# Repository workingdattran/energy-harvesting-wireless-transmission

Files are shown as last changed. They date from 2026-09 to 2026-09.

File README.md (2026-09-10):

# Energy Harvesting & Wireless Data Transmission System

## Overview
This repository contains the hardware schematics and firmware source code for a self-sustaining IoT system that harvests solar energy and transmits real-time telemetry data[cite: 1]. Developed as a course project for Information Theory at Hanoi University of Science and Technology (HUST)[cite: 1], the system utilizes a Joule Thief circuit to boost low-voltage solar power into a supercapacitor, and an ESP32-S3 microcontroller to transmit voltage data via the ESP-NOW protocol[cite: 1]. 

To optimize bandwidth and energy consumption, the firmware implements data compression using Differential Pulse Code Modulation (DPCM) combined with Huffman coding, compressing 32-bit floating-point data down to a single bit during stable charging states[cite: 1].

## System Architecture

The architecture is built upon the classic Shannon communication model, consisting of two main nodes[cite: 1]:

### 1. Transmitter Node (ESP32-S3 + Joule Thief)
*   **Energy Harvesting:** A 3V / 210 mA polycrystalline solar panel powers a custom blocking oscillator (Joule Thief) using a 2N2222 NPN transistor, a bifilar ferrite toroid (15 turns), and a 1N5822 Schottky diode[cite: 1].
*   **Storage & Protection:** Energy is stored in a 5.5V - 1F supercapacitor[cite: 1]. A TL431 shunt regulator paired with a 47kΩ voltage divider caps the voltage at 5.0V to protect the supercapacitor, while keeping static leakage current minimal (~0.05 mA)[cite: 1].
*   **ADC Processing:** The ESP32-S3 reads the capacitor's voltage via its 12-bit ADC, utilizing a 64-sample oversampling technique and linear calibration to eliminate quantization noise[cite: 1].
*   **Source Coding:** 
    *   **DPCM:** Calculates the prediction error of the voltage based on charging inertia[cite: 1].
    *   **Huffman Coding:** Encodes the error into variable-length bit streams, dynamically reducing payload size[cite: 1].

### 2. Receiver Node (ESP32-S3)
*   Operates continuously in RX mode[cite: 1].
*   Receives payload via ESP-NOW, decodes the Huffman sequence, reconstructs the original voltage using inverse DPCM, and outputs performance metrics via UART (115200 baud) for logging[cite: 1].

## Hardware Bill of Materials (BOM)
| Component | Specification | Purpose |
| :--- | :--- | :--- |
| **MCU** | 2x ESP32-S3 Dev Module | Processing & ESP-NOW Tx/Rx[cite: 1] |
| **Solar Panel** | Polycrystalline 3V / 210mA (70x70mm) | Power source[cite: 1] |
| **Transistor** | NPN 2N2222 (TO-92) | Oscillator switch[cite: 1] |
| **Diode** | Schottky 1N5822 | High-frequency rectification[cite: 1] |
| **Inductor** | Bifilar wound ferrite core (15 turns) | Flyback transformer[cite: 1] |
| **Capacitor** | 5.5V - 1F Supercapacitor | Energy storage[cite: 1] |
| **IC** | TL431 Shunt Regulator | Overvoltage protection[cite: 1] |
| **Resistors** | 1kΩ, 2x 47kΩ | Base biasing & Voltage divider[cite: 1] |

## Performance Metrics
Based on laboratory experiments processing 2,286 packets, the system achieved the following metrics[cite: 1]:
*   **Maximum Compression Ratio:** 32.0x (Payload reduced from 32-bit float to 1-bit during ideal tracking)[cite: 1].
*   **Transmission Latency:** 804 µs median delay[cite: 1].
*   **Reliability:** 0.31% total packet error rate (PER) with an automated MAC-layer CRC integrity check[cite: 1].
*   **Throughput:** 14.93 Bytes per second (average), effectively freeing up the 2.4 GHz spectrum[cite: 1].

## Build & Flash Instructions
1.  Clone this repository to your local machine.
2.  Open the project using **PlatformIO** or **Arduino IDE** (ensure ESP32 board support is installed).
3.  Upload the `Tx_Node` directory code to the first ESP32-S3.
4.  Upload the `Rx_Node` directory code to the second ESP32-S3.
5.  Open the Serial Monitor (115200 baud) on the Receiver Node to view real-time decoded voltage and transmission metrics.

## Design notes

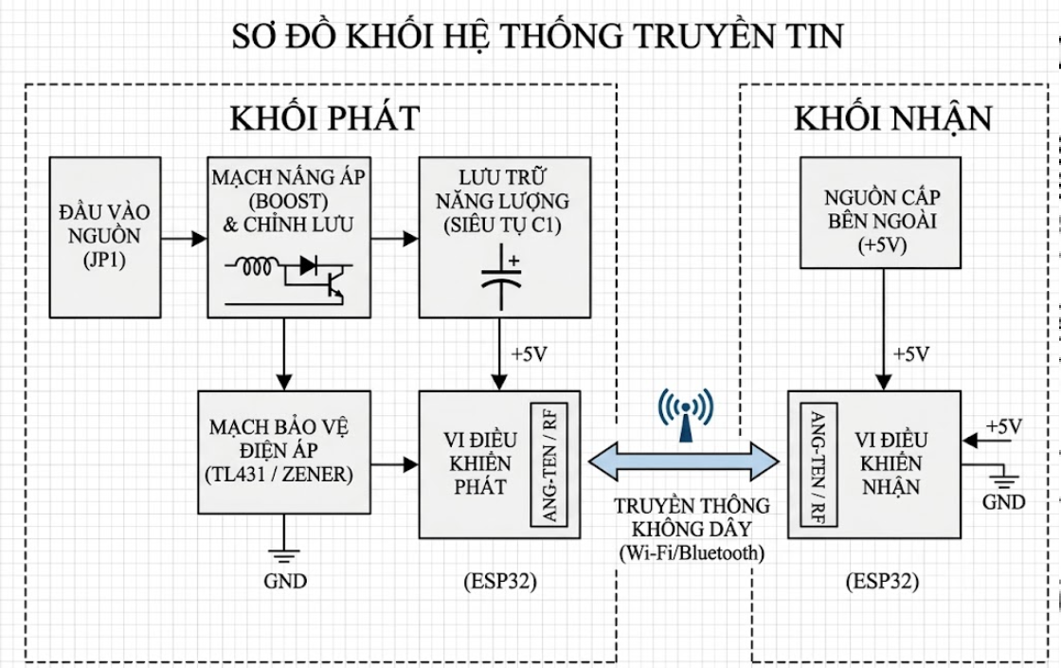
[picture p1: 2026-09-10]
energy harvesting/Altium designed/assets/sodo_khoi.png

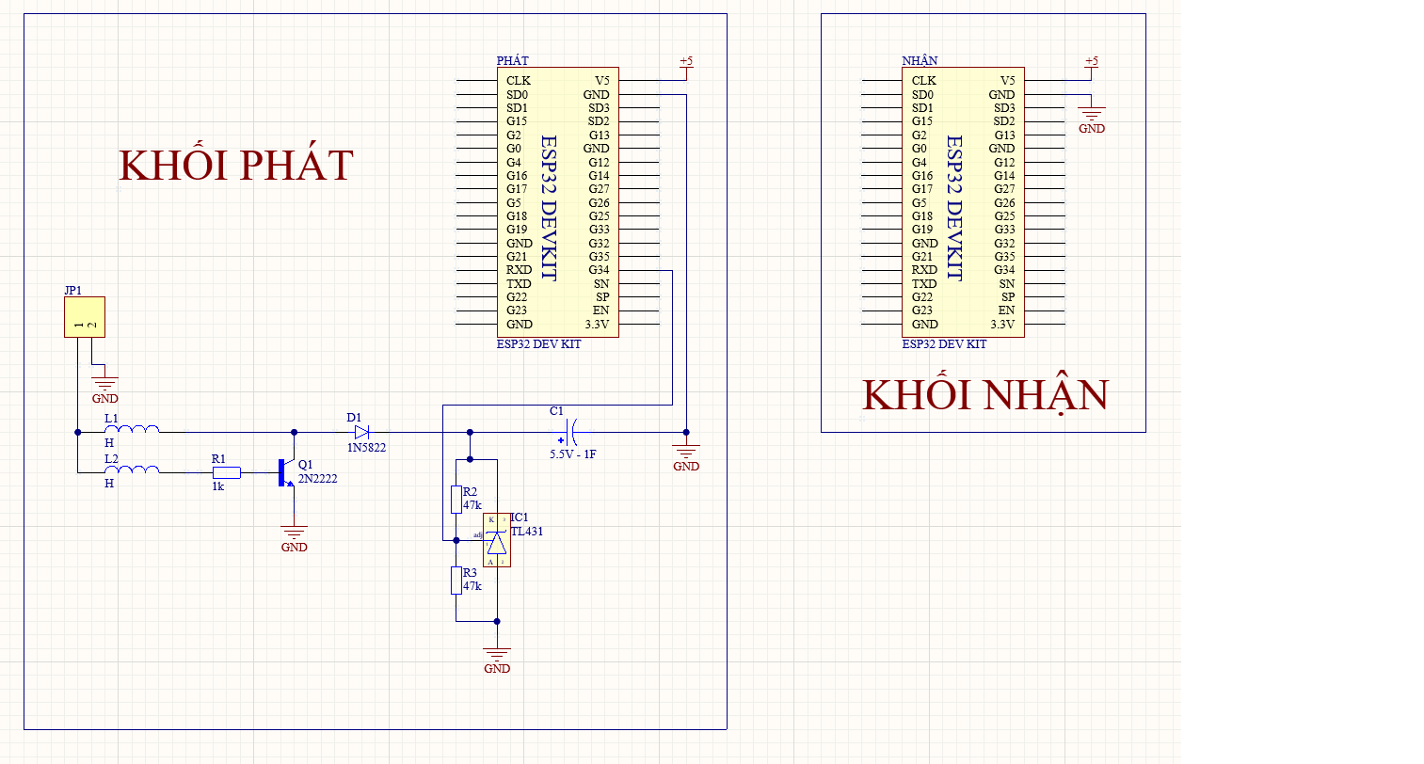
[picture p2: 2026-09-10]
energy harvesting/Altium designed/assets/sodonguyenly.png

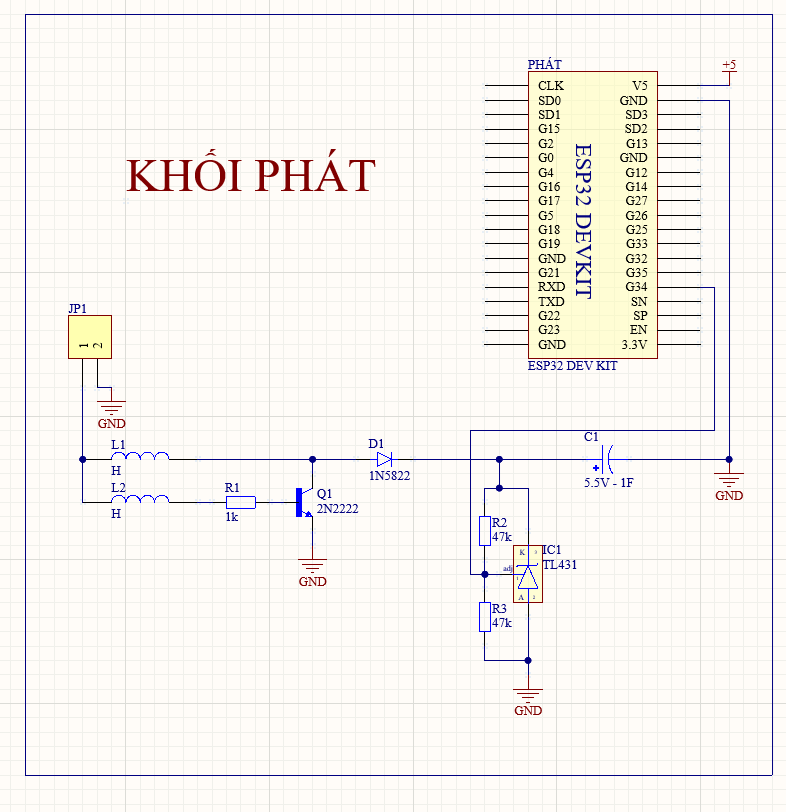
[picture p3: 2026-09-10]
energy harvesting/Altium designed/assets/PHÁT.png

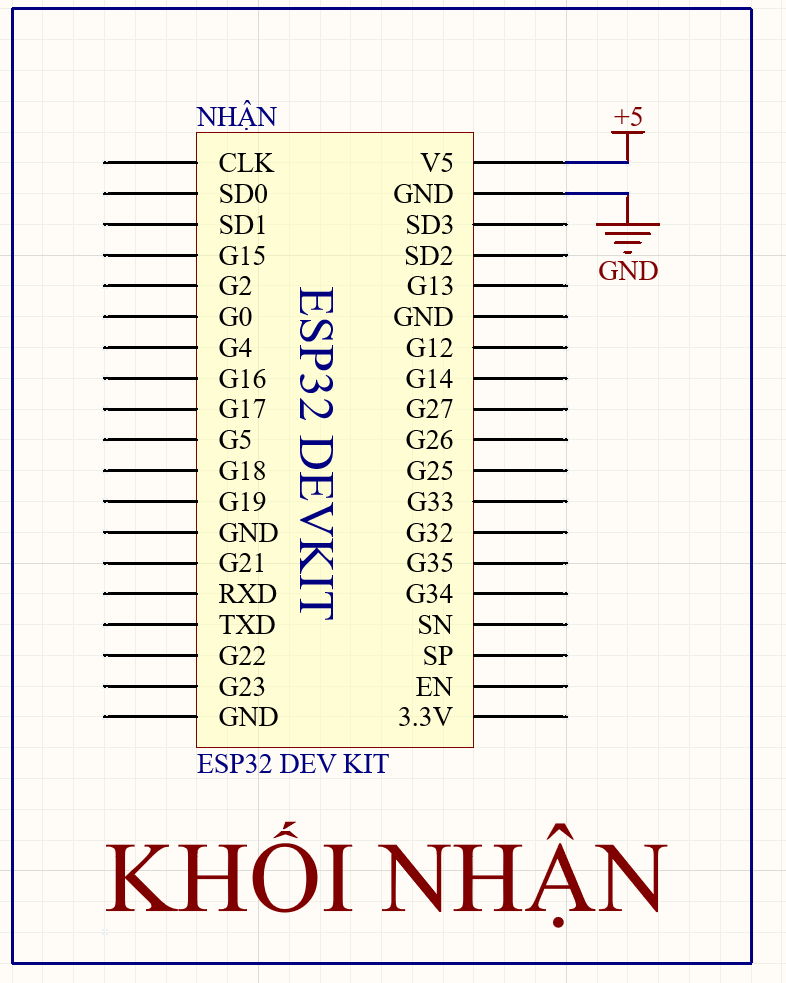
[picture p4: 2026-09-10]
energy harvesting/Altium designed/assets/NHẬN.png

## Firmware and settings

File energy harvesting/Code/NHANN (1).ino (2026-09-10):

#include <esp_now.h>
#include <WiFi.h>
#include <esp_wifi.h>
#include <HTTPClient.h>
#include <ArduinoJson.h>

// --- THÔNG TIN WIFI VÀ GOOGLE SHEETS ---
const char* ssid = "depzailatengoi";
const char* password = "tranducdat";
const char* scriptUrl = "https://script.google.com/macros/s/AKfycbxbDeGb_7TwyR9PDk_l7dfxE3b5P4eicFt4YnIJgVGBVs9WbP96MlSlnLDNgulAzeRiyw/exec";

unsigned long lastPrintTime = 0;
const unsigned long printInterval = 250;

#pragma pack(push, 1)
typedef struct struct_message {
  uint32_t packetID;
  uint8_t isKeyFrame; 
  float lossRate;     
  uint32_t txDelay;   
  union {
    float dienApGoc;
    struct {
      uint16_t code;
      uint8_t bitLen;
    } huffman;
  } payload;
} struct_message;
#pragma pack(pop)

struct_message myData;

float dienApHienTai = 0.0;
int dienApHienTai_mV = 0;
int tocDoTruoc_mV = 0;

float phat_lossRate = 0.0;
uint32_t phat_txDelay = 0;

uint32_t expectedPacketID = 0;
unsigned long tongSoGoiBiMat = 0;
unsigned long tongSoGoiDaNhan = 0;
unsigned long tongSoByteDaNhan = 0;
unsigned long thoiGianBatDauNhan = 0;

float packetLossRate = 0.0;
float throughput = 0.0;

volatile bool coDuLieuMoi = false; 
volatile bool laGoiGoc = false; 

int decodeHuffman(uint16_t code, uint8_t bitLen) {
  if (bitLen == 1 && code == 0b0) return 0;
  if (bitLen == 2 && code == 0b10) return 1;
  if (bitLen == 3 && code == 0b110) return -1;
  if (bitLen == 4 && code == 0b1110) return 2;
  if (bitLen == 5 && code == 0b11110) return -2;
  if (bitLen == 13) return (int8_t)(code & 0xFF); 
  return 0; 
}

void OnDataRecv(const esp_now_recv_info_t *esp_now_info, const uint8_t *incomingData, int len) {
  unsigned long thoiGianHienTai = millis();
  memcpy(&myData, incomingData, sizeof(myData));
  
  if (tongSoGoiDaNhan == 0) thoiGianBatDauNhan = thoiGianHienTai;

  laGoiGoc = myData.isKeyFrame; 
  phat_lossRate = myData.lossRate; 
  phat_txDelay = myData.txDelay;   

  // 1. GIẢI MÃ QUÁN TÍNH DPCM
  if (laGoiGoc) {
    dienApHienTai = myData.payload.dienApGoc;
    dienApHienTai_mV = round(dienApHienTai * 1000.0);
    tocDoTruoc_mV = 0; 
  } else {
    int saiSo_mV = decodeHuffman(myData.payload.huffman.code, myData.payload.huffman.bitLen);
    
    int dienApDuDoan_mV = dienApHienTai_mV + tocDoTruoc_mV;
    int dienApMoi_mV = dienApDuDoan_mV + saiSo_mV;
    int dienApCu_mV = dienApHienTai_mV; 
    
    dienApHienTai_mV = dienApMoi_mV;
    dienApHienTai = dienApHienTai_mV / 1000.0;
    
    tocDoTruoc_mV = dienApHienTai_mV - dienApCu_mV; 
  }

  // 2. THỐNG KÊ TRUYỀN TIN
  if (tongSoGoiDaNhan == 0) expectedPacketID = myData.packetID;
  if (myData.packetID > expectedPacketID) tongSoGoiBiMat += (myData.packetID - expectedPacketID);
  
  expectedPacketID = myData.packetID + 1;
  tongSoGoiDaNhan++;

  packetLossRate = ((float)tongSoGoiBiMat / (tongSoGoiDaNhan + tongSoGoiBiMat)) * 100.0;

  tongSoByteDaNhan += len;
  float thoiGianChay_s = (thoiGianHienTai - thoiGianBatDauNhan) / 1000.0;
  if (thoiGianChay_s > 0) throughput = tongSoByteDaNhan / thoiGianChay_s;

  coDuLieuMoi = true;
}

// HÀM ĐẨY DỮ LIỆU LÊN GOOGLE SHEETS
void sendToGoogleSheets(String loaiGoiStr) {
  if (WiFi.status() == WL_CONNECTED) {
    HTTPClient http;

    // --- 1. GỬI DỮ LIỆU CỦA NODE PHÁT (TX) ---
    http.begin(scriptUrl);
    http.addHeader("Content-Type", "application/json");
    StaticJsonDocument<200> docTX;
    docTX["nodeType"] = "TX";
    docTX["packetID"] = myData.packetID;
    docTX["dienAp"] = dienApHienTai;
    docTX["loaiGoi"] = loaiGoiStr;
    docTX["txLoss"] = phat_lossRate;
    docTX["txDelay"] = phat_txDelay;
    
    String reqTX; serializeJson(docTX, reqTX);
    http.POST(reqTX);
    http.end();

    // --- 2. GỬI DỮ LIỆU CỦA NODE NHẬN (RX) ---
    http.begin(scriptUrl);
    http.addHeader("Content-Type", "application/json");
    StaticJsonDocument<200> docRX;
    docRX["nodeType"] = "RX";
    docRX["packetID"] = myData.packetID;
    docRX["dienAp"] = dienApHienTai;
    docRX["loaiGoi"] = loaiGoiStr;
    docRX["rxLoss"] = packetLossRate;
    docRX["bangThong"] = throughput;
    
    String reqRX; serializeJson(docRX, reqRX);
    http.POST(reqRX);
    http.end();
  } else {
    Serial.println("Lỗi kết nối WiFi, không thể gửi lên Sheets");
  }
}

void setup() {
  Serial.begin(115200);
  
  // 1. Kết nối WiFi để lấy Internet
  WiFi.mode(WIFI_STA);
  WiFi.begin(ssid, password);
  
  Serial.print("Connecting to WiFi");
  while (WiFi.status() != WL_CONNECTED) {
    delay(500);
    Serial.print(".");
  }
  Serial.println("\nWiFi Connected!");
  delay(1000);
  
  // Lấy kênh WiFi hiện tại của Router
  int wifiChannel = WiFi.channel();
  
  // 2. Khởi tạo ESP-NOW ĐỒNG BỘ với kênh WiFi của Router
  esp_wifi_set_promiscuous(true);
  esp_wifi_set_channel(wifiChannel, WIFI_SECOND_CHAN_NONE);
  esp_wifi_set_promiscuous(false);

  if (esp_now_init() != ESP_OK) {
    Serial.println("Lỗi khởi tạo ESP-NOW");
    return;
  }
  esp_now_register_recv_cb(OnDataRecv);
  
  Serial.print("--- KÊNH HOẠT ĐỘNG: "); Serial.print(wifiChannel); Serial.println(" ---");
  Serial.println("--- NHẬN: ĐÃ KÍCH HOẠT GIẢI MÃ PREDICTIVE CODING ---");
}

void loop() {
  // Tạo biến static để đếm thời gian riêng cho việc gửi lên Sheets
  static unsigned long lastSendTime = 0;
  const unsigned long sendInterval = 5000; // Thay đổi số này (ms) để chỉnh tần suất gửi Sheets (ví dụ 5000 = 5 giây)

  if (millis() - lastPrintTime >= printInterval) { 
    lastPrintTime = millis();
    
    if (coDuLieuMoi) {
      coDuLieuMoi = false; 
      String loaiGoiStr = laGoiGoc ? "GOC" : "HUF";

      // 1. In log ra Serial (Chạy mượt mà theo đúng printInterval)
      Serial.print("Ap: ");
      Serial.print(dienApHienTai, 3); Serial.print("V | ");
      Serial.print("GOI: "); Serial.print(loaiGoiStr);
      Serial.print(" | MAT GOI RX: "); Serial.print(packetLossRate, 1); Serial.print("% | ");
      Serial.print("BANG THONG: "); Serial.print(throughput, 1); Serial.println(" Bps");

      // 2. Gửi dữ liệu lên Sheets (Được tách riêng rẽ, chỉ chạy khi đủ thời gian sendInterval)
      if (millis() - lastSendTime >= sendInterval) {
        lastSendTime = millis();
        sendToGoogleSheets(loaiGoiStr);
      }
    }
  }
}

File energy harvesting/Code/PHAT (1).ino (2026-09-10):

#include <esp_now.h>
#include <WiFi.h>
#include <esp_wifi.h>

// Đã đổi sang chân 34 để tránh xung đột với TX0 (chân 1) của cổng Serial
#define PIN_DO_AP 6 
float HE_SO_PHAN_AP = 2.0; 
float VI_CHINH_OFFSET1 = 0.007; 

uint8_t receiverAddress[] = {0x70, 0x4B, 0xCA, 0x6E, 0x3B, 0xC8};

#pragma pack(push, 1)
typedef struct struct_message {
  uint32_t packetID;
  uint8_t isKeyFrame; 
  float lossRate;     
  uint32_t txDelay;   
  union {
    float dienApGoc;  
    struct { 
      uint16_t code;  
      uint8_t bitLen; 
    } huffman;
  } payload;
} struct_message;
#pragma pack(pop)

struct_message myData;
esp_now_peer_info_t peerInfo;

// Các biến phục vụ Mã hóa dự đoán (DPCM)
int dienApTruoc_mV = 0;
int tocDoTruoc_mV = 0; 
unsigned long tongSoGoiDaGui = 0;
unsigned long soGoiLoiACK = 0;

// Các biến volatile để sử dụng đồng bộ giữa callback và loop
volatile uint32_t thoiGianTreTruocDo = 0; 
volatile unsigned long timeStart = 0;    

// THÊM: Các biến phục vụ việc định thời gian bằng millis()
unsigned long thoiGianDoCu = 0;
unsigned long thoiGianGuiCu = 0;
float dienApDaLocHienTai = 0.0;

void encodeHuffman(int saiSo_mV) {
  myData.isKeyFrame = 0;
  if (saiSo_mV == 0)       { myData.payload.huffman.bitLen = 1; myData.payload.huffman.code = 0b0; }
  else if (saiSo_mV == 1)  { myData.payload.huffman.bitLen = 2; myData.payload.huffman.code = 0b10; }
  else if (saiSo_mV == -1) { myData.payload.huffman.bitLen = 3; myData.payload.huffman.code = 0b110; }
  else if (saiSo_mV == 2)  { myData.payload.huffman.bitLen = 4; myData.payload.huffman.code = 0b1110; }
  else if (saiSo_mV == -2) { myData.payload.huffman.bitLen = 5; myData.payload.huffman.code = 0b11110; }
  else { 
    uint8_t safeSaiSo = (uint8_t)saiSo_mV;
    myData.payload.huffman.bitLen = 13; 
    myData.payload.huffman.code = (0b11111 << 8) | safeSaiSo; 
  }
}

// Hàm callback chuẩn của ESP-NOW để nhận phản hồi (ACK)
void OnDataSent(const wifi_tx_info_t *txInfo, esp_now_send_status_t status) {
  if (status == ESP_NOW_SEND_SUCCESS) {
    // Nhận được ACK -> Tính thời gian RTT chia đôi để ra độ trễ 1 chiều
    thoiGianTreTruocDo = (uint32_t)((micros() - timeStart) / 2); 
  } else {
    // Mất gói tin (không nhận được ACK)
    soGoiLoiACK++;
  }
}

// BỘ LỌC: TRIMMED MEAN KẾT HỢP EMA (CHỐNG NHIỄU TUYỆT ĐỐI)
float dienApDaLoc = -1.0; 
const float ALPHA = 0.5; 

float docDienApChuan(int pin) {
  int rawValues[64];
  
  // 1. Lấy 64 mẫu liên tục
  for(int i = 0; i < 64; i++) {
    rawValues[i] = analogReadMilliVolts(pin);
  }
  
  // 2. Bubble Sort
  for(int i = 0; i < 63; i++) {
    for(int j = i + 1; j < 64; j++) {
      if(rawValues[i] > rawValues[j]) {
        int temp = rawValues[i];
        rawValues[i] = rawValues[j];
        rawValues[j] = temp;
      }
    }
  }
  
  // 3. Trimmed Mean (Lọc 32 mẫu giữa)
  long tong_mV = 0;
  for(int i = 16; i < 48; i++) {
    tong_mV += rawValues[i];
  }
  float dienApTucThoi = (tong_mV / 32.0) / 1000.0;
  
  // 4. SMART EMA FILTER (Lọc thông minh)
  if (dienApDaLoc < 0) {
    dienApDaLoc = dienApTucThoi; // Gán lần đầu
  } else {
    // Nếu độ lệch giữa số cũ và số thực tế lớn hơn 0.03V (30mV)
    // -> Báo hiệu có sự kiện cắm/rút tụ đột ngột -> Nhảy số ngay lập tức
    if (abs(dienApTucThoi - dienApDaLoc) > 0.03) {
      dienApDaLoc = dienApTucThoi; 
    } 
    // Nếu biến động nhỏ -> Do nhiễu -> Kích hoạt lọc EMA chậm rãi
    else {
      dienApDaLoc = (ALPHA * dienApTucThoi) + ((1.0 - ALPHA) * dienApDaLoc);
    }
  }
  
  return dienApDaLoc;
}

void setup() {
  Serial.begin(115200);
  analogSetPinAttenuation(PIN_DO_AP, ADC_11db);
  WiFi.mode(WIFI_STA);
  esp_wifi_set_ps(WIFI_PS_NONE);
  esp_wifi_set_channel(11, WIFI_SECOND_CHAN_NONE);
  
  if (esp_now_init() != ESP_OK) return;
  esp_now_register_send_cb(OnDataSent);
  
  memcpy(peerInfo.peer_addr, receiverAddress, 6);
  peerInfo.peer_addr[0] = receiverAddress[0];
  peerInfo.channel = 11;  
  peerInfo.encrypt = false;
  esp_now_add_peer(&peerInfo);
  
  Serial.println("--- PHÁT: ĐÃ KÍCH HOẠT LỌC NHIỄU & DPCM + HUFFMAN ---");
}

void loop() {
  unsigned long thoiGianHienTai = millis();

  // ==============================================================
  // CHU KỲ 1: ĐO VÀ LỌC ĐIỆN ÁP LIÊN TỤC MỖI 20ms (50 lần/giây)
  // ==============================================================
  if (thoiGianHienTai - thoiGianDoCu >= 20) {
    dienApDaLocHienTai = docDienApChuan(PIN_DO_AP);
    thoiGianDoCu = thoiGianHienTai;
  }

  // ==============================================================
  // CHU KỲ 2: TÍNH TOÁN, ĐÓNG GÓI, GỬI VÀ IN DỮ LIỆU MỖI 1000ms
  // ==============================================================
  if (thoiGianHienTai - thoiGianGuiCu >= 1000) {
    
    float dienApChanDo = dienApDaLocHienTai;
    
    // Tinh chỉnh sai số theo phân khúc
    if (dienApChanDo * HE_SO_PHAN_AP <= 3.0) {
      dienApChanDo += 0.014;
    }
    else if (dienApChanDo * HE_SO_PHAN_AP <= 4.0) {
      dienApChanDo += 0.007;
    }
    else {
      dienApChanDo += 0.007;
    }
    
    // Nhân hệ số phân áp để quy đổi ra mức điện áp thật
    float dienApTuHienTai = dienApChanDo * HE_SO_PHAN_AP;
    
    tongSoGoiDaGui++;
    
    int dienApHienTai_mV = round(dienApTuHienTai * 1000.0);
    int dienApDuDoan_mV = dienApTruoc_mV + tocDoTruoc_mV; 
    int saiSo_mV = dienApHienTai_mV - dienApDuDoan_mV;

    if (tongSoGoiDaGui % 5 == 1 || saiSo_mV > 127 || saiSo_mV < -128) {
      myData.isKeyFrame = 1;
      myData.payload.dienApGoc = dienApTuHienTai;
      dienApTruoc_mV = dienApHienTai_mV;
      tocDoTruoc_mV = 0; 
    } else {
      encodeHuffman(saiSo_mV);
      tocDoTruoc_mV = dienApHienTai_mV - dienApTruoc_mV;
      dienApTruoc_mV = dienApHienTai_mV;
    }

    float lossRate = ((float)soGoiLoiACK / tongSoGoiDaGui) * 100.0;
    
    // 1. Đóng gói đầy đủ dữ liệu
    myData.packetID = tongSoGoiDaGui;
    myData.lossRate = lossRate; 
    myData.txDelay = thoiGianTreTruocDo; // Nhúng độ trễ của lần gửi trước vào gói này

    // 2. Chốt mốc thời gian bắt đầu gửi
    timeStart = micros();
    
    // 3. Thực thi lệnh gửi
    esp_now_send(receiverAddress, (uint8_t *) &myData, sizeof(myData));
    
    // In thông tin ra màn hình
    Serial.print(" Áp: "); Serial.print(dienApTuHienTai, 3); Serial.print("V | ");
    if (myData.isKeyFrame) {
      Serial.print("GÓI GỐC (32-bit) | ");
    } else {
      float ratio = 32.0 / myData.payload.huffman.bitLen;
      Serial.print("HUFFMAN ("); Serial.print(myData.payload.huffman.bitLen);
      Serial.print(" bit) -> NÉN: "); Serial.print(ratio, 1); Serial.print("x | ");
    }
    Serial.print("LỖI ĐƯỜNG TRUYỀN: "); Serial.print(lossRate, 1);
    Serial.print("% | TRỄ: "); Serial.print(thoiGianTreTruocDo); Serial.println(" us");

    // Cập nhật lại mốc thời gian gửi
    thoiGianGuiCu = thoiGianHienTai;
  }
}
